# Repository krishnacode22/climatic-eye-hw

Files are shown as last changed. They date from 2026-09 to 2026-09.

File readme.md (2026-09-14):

# Climatic Eye — Solar-Powered IoT Weather Station

An open-source, solar-powered environmental monitoring station built around the **ESP32** microcontroller. Climatic Eye collects real-time weather and soil data, transmits it wirelessly over **LoRa** (RA-02 433 MHz), and serves a live debug dashboard over Wi-Fi — all without requiring an internet connection.

**Author:** Krishna Singh

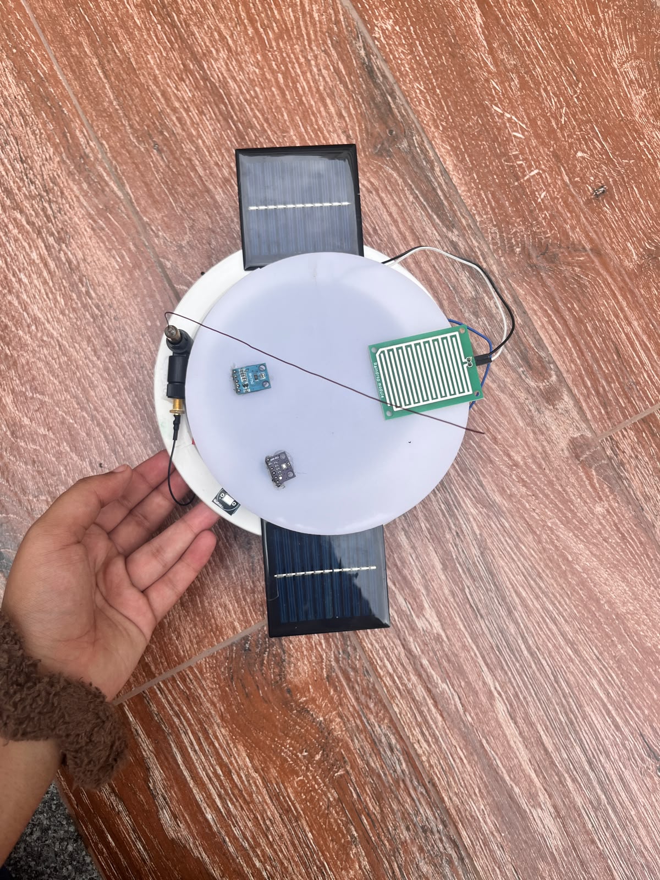
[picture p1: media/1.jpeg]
Top view — sensors and solar panels mounted on the enclosure


---

## Table of Contents

- [Features](#features)
- [Build Gallery](#build-gallery)
- [Hardware Components](#hardware-components)
- [Wiring and Pin Map](#wiring-and-pin-map)
- [Software Overview](#software-overview)
- [Getting Started](#getting-started)
- [Viewing the Schematic in Fritzing](#viewing-the-schematic-in-fritzing)
- [Repository Structure](#repository-structure)
- [Sensor Calibration](#sensor-calibration)
- [License](#license)
- [Contributing](#contributing)

---

## Features

- **Multi-sensor environmental monitoring** — temperature, humidity, barometric pressure, ambient light, rainfall, soil moisture, and GPS location.
- **LoRa long-range telemetry** — transmits JSON sensor packets via RA-02 (433 MHz) for remote data collection.
- **Solar-powered** — dual solar panels with Li-ion 18650 battery backup and TP4056 charge controller.
- **Built-in Wi-Fi dashboard** — the ESP32 hosts a responsive admin/debug web page accessible from any phone or laptop.
- **Self-contained operation** — creates its own Wi-Fi hotspot (AP mode) by default; optionally connects to an existing router (STA mode).
- **GPS geotagging** — each telemetry packet includes latitude, longitude, and satellite count from a NEO-6M GPS module.
- **Interpreted conditions** — firmware translates raw readings into human-readable states (e.g. "Comfortable", "Rain detected", "Overcast").

---

## Build Gallery

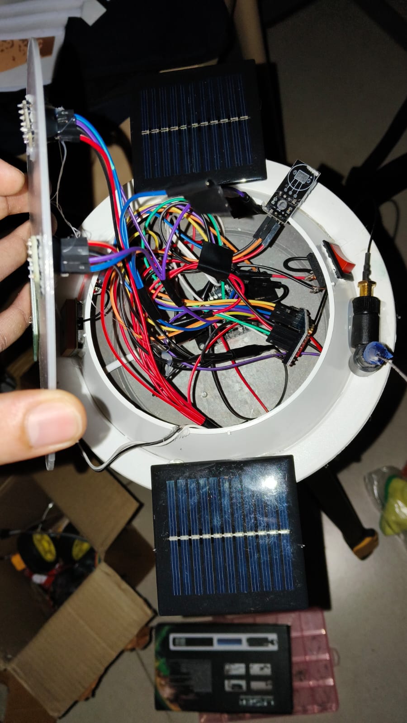
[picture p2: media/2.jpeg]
Internal wiring — ESP32, sensors, and LoRa module inside the enclosure


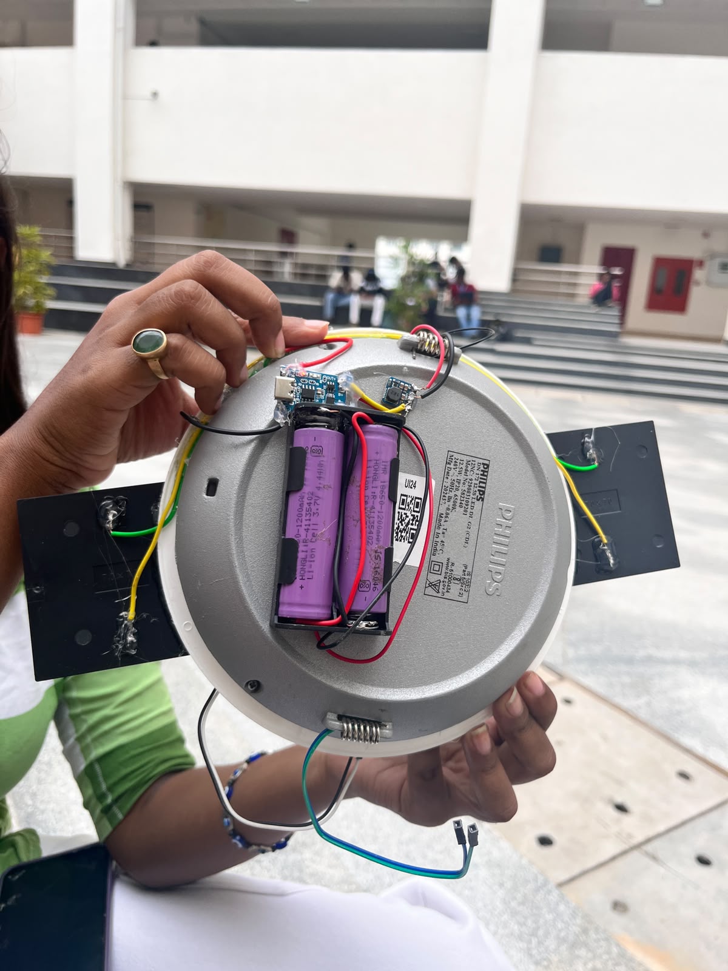
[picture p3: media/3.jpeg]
Power system — 18650 Li-ion batteries with TP4056 charge controller and solar panels


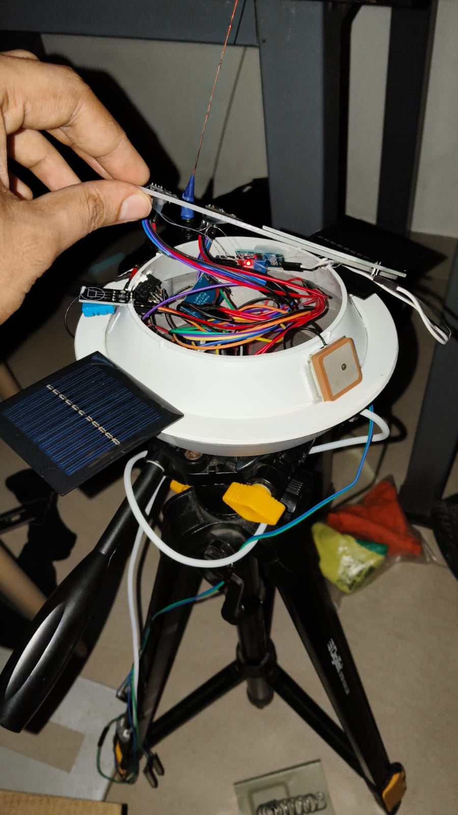
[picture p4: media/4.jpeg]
Assembled prototype on tripod — internal view with GPS antenna visible


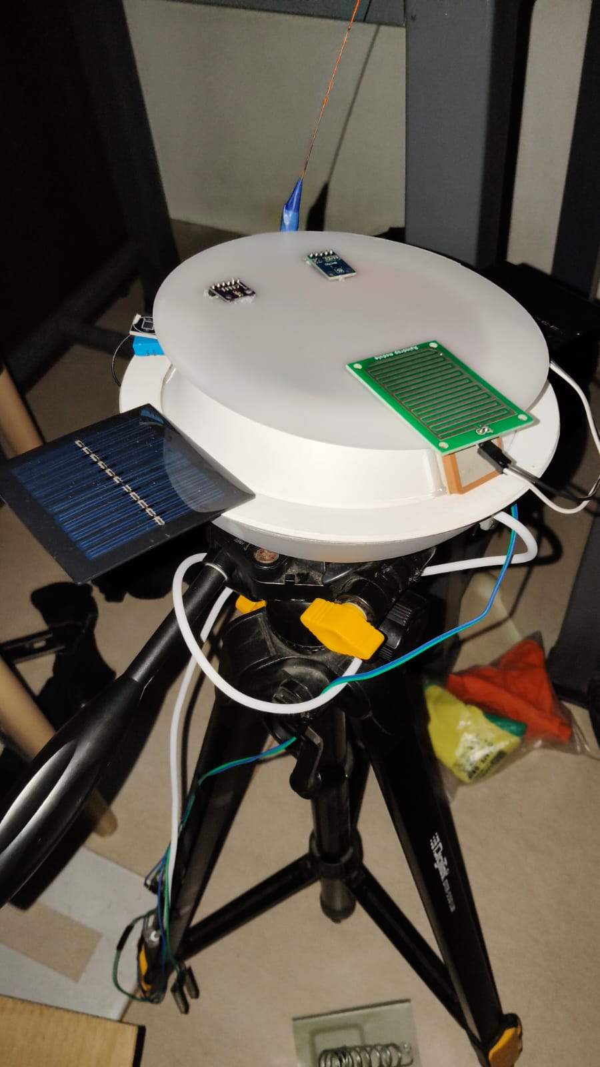
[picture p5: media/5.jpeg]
Completed unit on tripod — top view showing sensor plate, rain sensor, and solar panel


---

## Hardware Components

| Component | Purpose |
|---|---|
| ESP32 DevKit | Main microcontroller (Wi-Fi + BLE) |
| DHT11 | Temperature and humidity sensing |
| BMP280 | Barometric pressure and altitude |
| BH1750 | Ambient light intensity (lux) |
| Raindrop sensor (YL-83) | Rainfall detection (analog) |
| Soil moisture sensor (FC-28) | Soil moisture level (analog) |
| NEO-6M GPS | Latitude, longitude, and satellite tracking |
| RA-02 LoRa (SX1278) | 433 MHz long-range radio transmission |
| TP4056 charge module | Li-ion battery charging from solar input |
| 18650 Li-ion batteries (x2) | Rechargeable power supply |
| Solar panels (x2) | Energy harvesting |

---

## Wiring and Pin Map

### I2C Bus (BMP280 and BH1750)

| Signal | ESP32 GPIO |
|---|---|
| SDA | GPIO 21 |
| SCL | GPIO 22 |

### NEO-6M GPS (UART2)

| Signal | ESP32 GPIO |
|---|---|
| GPS TX | GPIO 16 (RX2) |
| GPS RX | GPIO 17 (TX2) |

### DHT11

| Signal | ESP32 GPIO |
|---|---|
| DATA | GPIO 27 |

### Analog Sensors

| Signal | ESP32 GPIO |
|---|---|
| Rain AO | GPIO 34 |
| Soil AO | GPIO 35 |

### RA-02 LoRa (SPI)

| Signal | ESP32 GPIO |
|---|---|
| SCK | GPIO 18 |
| MISO | GPIO 19 |
| MOSI | GPIO 23 |
| NSS (CS) | GPIO 5 |
| RESET | GPIO 14 |
| DIO0 | GPIO 26 |

> A Fritzing schematic (`.fzz`) and exported wiring diagrams are available in the [`hardware/`](hardware/) folder. See [Viewing the Schematic in Fritzing](#viewing-the-schematic-in-fritzing) for installation instructions.

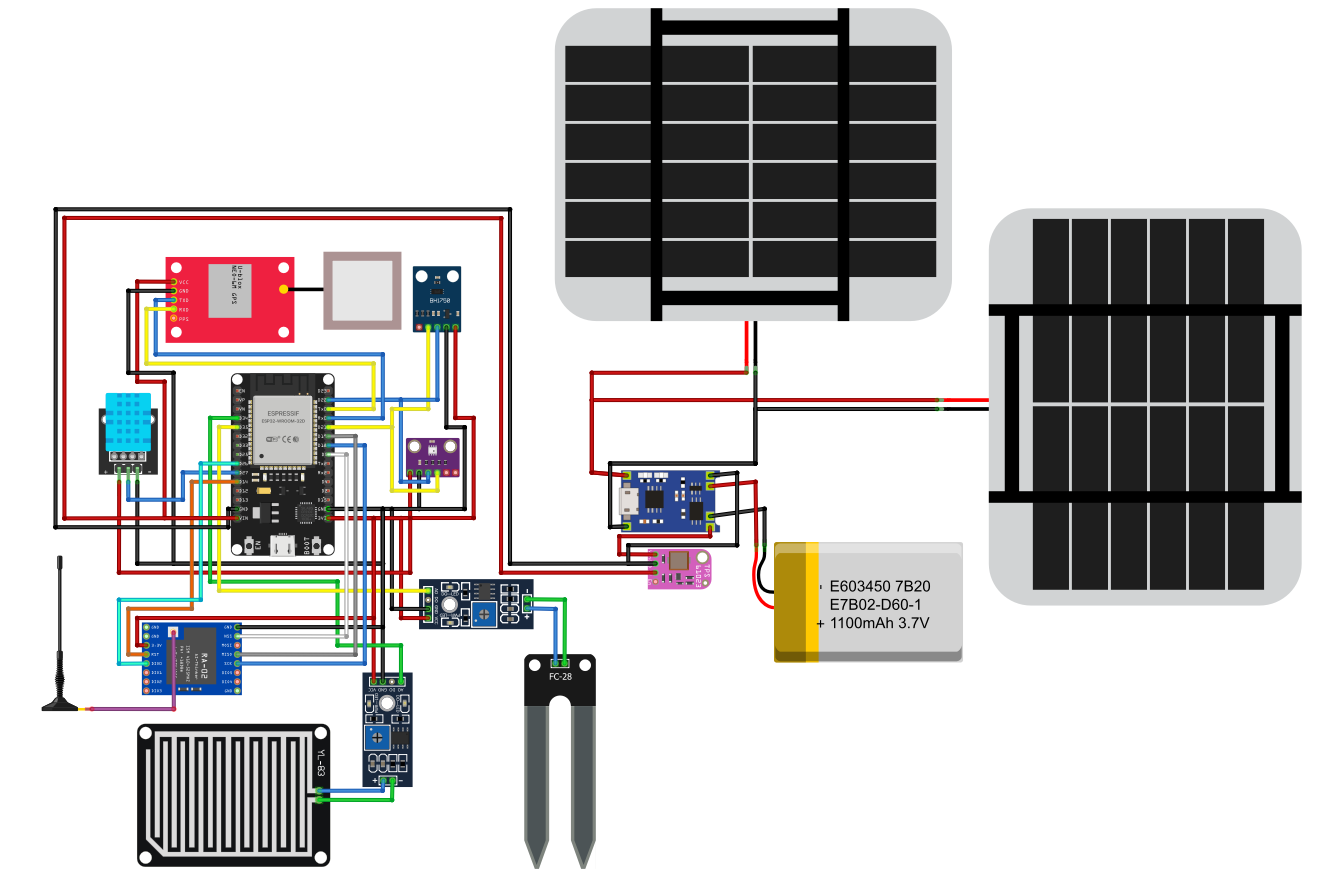
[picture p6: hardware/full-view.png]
Full circuit schematic


---

## Software Overview

### Firmware — [`ClimaticEye_Admin_Debug.ino`](software/ClimaticEye_Admin_Debug.ino)

The Arduino sketch performs the following operations:

1. **Sensor initialisation** — auto-detects BMP280 at address `0x76` or `0x77`, initialises BH1750, DHT11, GPS, and LoRa.
2. **Periodic reading** — samples all sensors every 5 seconds.
3. **JSON telemetry** — constructs a complete JSON payload containing raw values, interpreted states, and system status.
4. **LoRa transmission** — sends the JSON packet over 433 MHz LoRa.
5. **Wi-Fi web server** — serves the admin debug dashboard and exposes a `/api/data` JSON endpoint.
6. **Serial output** — prints formatted telemetry to the Serial Monitor at 115200 baud.

### Web Dashboard — [`index.html`](software/index.html)

A responsive, dark-themed, single-page dashboard that:

- Polls `/api/data` every 2 seconds.
- Displays live sensor readings with interpreted conditions.
- Shows system and sensor status (OK / FAILED) for each module.
- Provides raw ADC values and GPS coordinates.
- Includes a raw ESP32 diagnostic log panel.

### Required Arduino Libraries

| Library | Source |
|---|---|
| `WiFi` | Built-in (ESP32 core) |
| `WebServer` | Built-in (ESP32 core) |
| `Wire` / `SPI` | Built-in (Arduino core) |
| `Adafruit BMP280` | Adafruit BMP280 Library |
| `BH1750` | BH1750 by Christopher Laws |
| `DHT sensor library` | DHT sensor library by Adafruit |
| `TinyGPSPlus` | TinyGPSPlus by Mikal Hart |
| `LoRa` | LoRa by Sandeep Mistry |

---

## Getting Started

### 1. Clone the Repository

```bash
git clone https://github.com/<your-username>/climatic-eye-hw.git
```

### 2. Wire the Hardware

Follow the pin map above or refer to the [Climatic_Eye_Connection_Guide.pdf](hardware/Climatic_Eye_Connection_Guide.pdf) in the `hardware/` folder.

### 3. Flash the Firmware

1. Open [`software/ClimaticEye_Admin_Debug.ino`](software/ClimaticEye_Admin_Debug.ino) in the **Arduino IDE**.
2. Install the ESP32 board package and the required libraries listed above.
3. Select board: **ESP32 Dev Module**.
4. Set baud rate: **115200**.
5. Upload.

### 4. Access the Dashboard

By default the ESP32 creates a Wi-Fi hotspot with the following credentials:

| Setting | Value |
|---|---|
| SSID | `ClimaticEye-Debug` |
| Password | `climatic123` |
| Dashboard URL | `http://192.168.4.1` |

To connect to an existing router instead, set `STA_SSID` and `STA_PASSWORD` in the sketch before uploading. The ESP32 will attempt STA mode first and fall back to AP mode if the connection fails.

### 5. LoRa Frequency

The default LoRa frequency is **433 MHz** (`433E6`). If your RA-02 module operates at a different frequency, update the `LORA_FREQUENCY` constant in the sketch accordingly (e.g. `868E6` or `915E6`).

---

## Viewing the Schematic in Fritzing

The circuit schematic is provided as a [Fritzing](https://fritzing.org/) project file (`hardware/climatic-eye-schematic.fzz`). Fritzing is an open-source electronics design tool used to create breadboard layouts, schematics, and PCB designs.

### Installing Fritzing

1. Visit the official Fritzing download page: **[https://fritzing.org/download/](https://fritzing.org/download/)**
2. Fritzing is available for **Windows**, **macOS**, and **Linux**. Select the appropriate installer for your operating system.
3. Fritzing is distributed as a paid download (a small donation is requested to support ongoing development). Alternatively, the source code can be compiled from the [Fritzing GitHub repository](https://github.com/fritzing/fritzing-app).
4. Download and run the installer, or extract the portable archive to a directory of your choice.

### Opening the Schematic

1. Launch Fritzing.
2. Go to **File > Open** and navigate to `hardware/climatic-eye-schematic.fzz`.
3. The project will open in the **Breadboard** view. Use the tabs at the top to switch between **Breadboard**, **Schematic**, and **PCB** views.

Pre-exported wiring diagrams are also available as PNG images in the `hardware/` folder for those who prefer not to install Fritzing:

- [`full-view.png`](hardware/full-view.png) — complete circuit overview
- [`zoomed-esp32.png`](hardware/zoomed-esp32.png) — ESP32 wiring detail
- [`zoomed-power.png`](hardware/zoomed-power.png) — power circuit detail

---

## Repository Structure

```
climatic-eye-hw/
├── hardware/
│   ├── climatic-eye-schematic.fzz          # Fritzing schematic source file
│   ├── full-view.png                       # Full circuit diagram (exported)
│   ├── zoomed-esp32.png                    # ESP32 wiring detail (exported)
│   ├── zoomed-power.png                    # Power circuit detail (exported)
│   └── Climatic_Eye_Connection_Guide.pdf   # Printable wiring guide
├── software/
│   ├── ClimaticEye_Admin_Debug.ino         # ESP32 Arduino firmware
│   ├── index.html                          # Standalone web dashboard
│   └── setup-guide.png                     # Setup reference image
├── media/
│   ├── 1.jpeg                              # Build and prototype photographs
│   ├── 2.jpeg
│   ├── 3.jpeg
│   ├── 4.jpeg
│   └── 5.jpeg
└── readme.md
```

---

## Sensor Calibration

The raindrop and soil moisture sensors use analog ADC readings that must be calibrated for the specific modules in use. The default values in the firmware are as follows:

| Parameter | Default Value | Description |
|---|---|---|
| `RAIN_DRY_ADC` | 4095 | ADC reading when the rain sensor surface is dry |
| `RAIN_WET_ADC` | 1200 | ADC reading when the rain sensor surface is fully wet |
| `SOIL_DRY_ADC` | 3200 | ADC reading when the soil probe is in dry soil |
| `SOIL_WET_ADC` | 1400 | ADC reading when the soil probe is in saturated soil |

If the sensor readings are inverted (i.e. a wetter condition produces a higher ADC value), swap the DRY and WET values for the corresponding sensor.

---

## License

This project is open source. You are free to use, modify, and distribute it.

---

## Contributing

Contributions, bug reports, and feature requests are welcome. Please open an issue or submit a pull request.

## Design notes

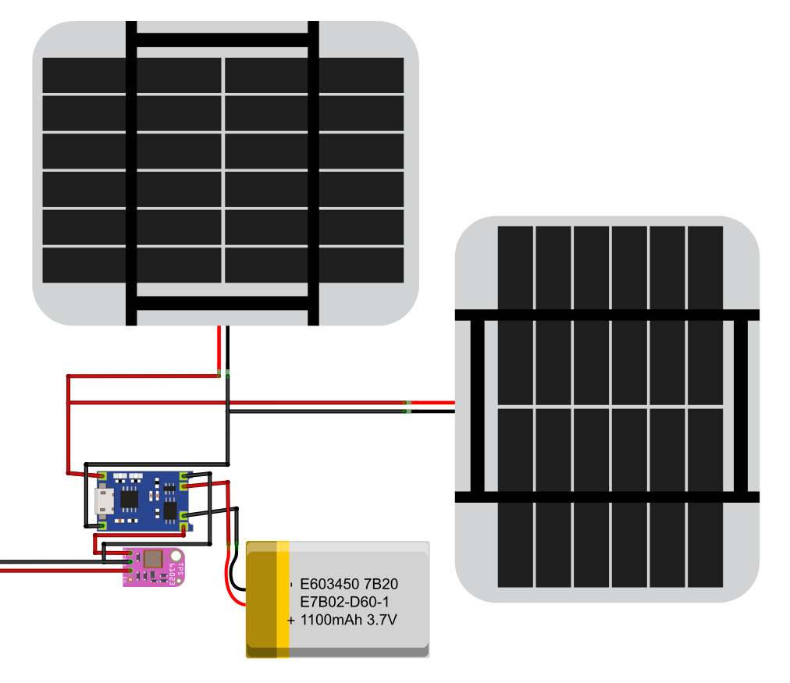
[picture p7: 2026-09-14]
hardware/zoomed-power.png

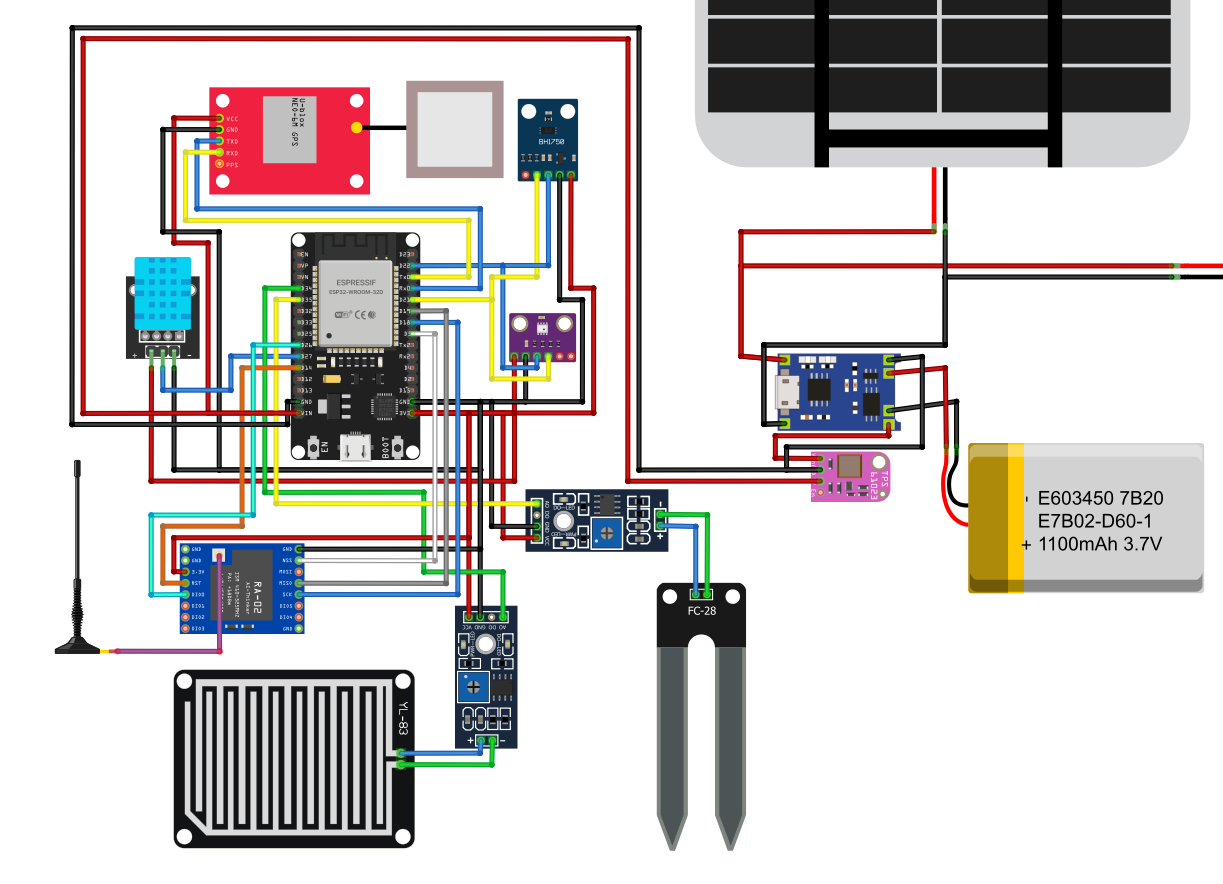
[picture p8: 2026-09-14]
hardware/zoomed-esp32.png

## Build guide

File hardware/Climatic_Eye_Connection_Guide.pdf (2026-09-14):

Climatic Eye | Hardware Connection Guide | Page 1

# CLIMATIC EYE

## Hardware Connection & Power Integration Guide

## ESP32-based environmental monitoring node

SYSTEM | CONFIGURATION
Controller | Generic 30-pin ESP32 DevKit
Environmental sensing | BMP280, BH1750, DHT11
Field sensing | Raindrop sensor, soil-moisture sensor
Positioning | NEO-6M GPS
Wireless link | RA-02 LoRa
Power | Solar panels, TP4056, Li-ion battery, 5 V boost converter

Document purpose
Use this guide as the wiring reference during assembly and bench testing. The GPIO allocation is kept consistent with the Climatic Eye firmware and admin debug dashboard.
Revision: Prototype Integration Guide | Bench assembly and field-node development

# 1. System Overview

The node combines environmental sensors, GPS, LoRa communications, and a solar-charged battery supply around a generic 30-pin ESP32. BMP280 and BH1750 share the I²C bus. The NEO-6M uses a dedicated hardware UART. The RA-02 uses the ESP32 VSPI pins. The raindrop and soil sensors use ADC inputs.

## Functional architecture

Solar panels → TP4056 → Li-ion battery → 5 V boost converter → ESP32 VIN/5V → ESP32 3.3 V rail → sensors + RA-02

Core rule
Keep all grounds common. Keep the RA-02 on 3.3 V only. Verify the boost-converter output with a multimeter before connecting it to the ESP32.

# 2. Complete GPIO Assignment

Device | Signal | ESP32 GPIO | Interface / note
BMP280 | SDA | GPIO 21 | I²C
BMP280 | SCL | GPIO 22 | I²C
BH1750 | SDA | GPIO 21 | Shares I²C with BMP280
BH1750 | SCL | GPIO 22 | Shares I²C with BMP280
NEO-6M | TX | GPIO 16 | ESP32 UART2 RX
NEO-6M | RX | GPIO 17 | ESP32 UART2 TX
DHT11 | DATA | GPIO 27 | Digital input
Raindrop module | AO | GPIO 34 | ADC input-only
Raindrop module | DO | Not connected | Analog reading used
Soil moisture module | AO | GPIO 35 | ADC input-only
Soil moisture module | DO | Not connected | Analog reading used
RA-02 | SCK | GPIO 18 | VSPI
RA-02 | MISO | GPIO 19 | VSPI
RA-02 | MOSI | GPIO 23 | VSPI
RA-02 | NSS / CS | GPIO 5 | Chip select
RA-02 | RESET | GPIO 14 | Reset control
RA-02 | DIO0 | GPIO 26 | LoRa interrupt

# 3. Sensor Connections

## 3.1 BMP280

BMP280 pin | ESP32 connection | Instruction
VCC / VIN | 3.3 V | Use 3.3 V.
GND | GND | Common ground.
SDA | GPIO 21 | I²C data.
SCL | GPIO 22 | I²C clock.

## 3.2 BH1750

BH1750 pin | ESP32 connection | Instruction
VCC | 3.3 V | Use 3.3 V.
GND | GND | Common ground.
SDA | GPIO 21 | Shares SDA with BMP280.
SCL | GPIO 22 | Shares SCL with BMP280.

I²C bus
BMP280 and BH1750 are connected in parallel on GPIO 21/22. If either is not detected, check power, ground, SDA/SCL orientation, and run an I²C scanner.

## 3.3 DHT11

DHT11 pin | ESP32 connection | Instruction
VCC | 3.3 V | Use 3.3 V.
GND | GND | Common ground.
DATA | GPIO 27 | Digital data line.

For a bare 4-pin DHT11, add approximately a 10 kΩ pull-up resistor between DATA and 3.3 V. Common 3-pin DHT11 modules normally include the pull-up resistor.

## 3.4 Raindrop sensor module

Module pin | ESP32 connection | Instruction
VCC | 3.3 V | Prefer 3.3 V so AO stays within the ESP32 ADC range.
GND | GND | Common ground.
AO | GPIO 34 | Analog measurement.
DO | Not connected | Not used by current firmware.

## 3.5 Soil-moisture sensor

Module pin | ESP32 connection | Instruction
VCC | 3.3 V | Prefer 3.3 V for ADC compatibility.
GND | GND | Common ground.

Module pin | ESP32 connection | Instruction
AO | GPIO 35 | Analog measurement.
DO | Not connected | Not used by current firmware.

# 4. GPS and LoRa Connections

## 4.1 NEO-6M GPS

NEO-6M pin | ESP32 connection | Instruction
VCC | 5 V/VIN or module-specified supply | Verify the exact breakout board.
GND | GND | Common ground.
TX | GPIO 16 | GPS TX → ESP32 UART2 RX.
RX | GPIO 17 | ESP32 UART2 TX → GPS RX.

GPS fix
Initial position acquisition can take time. Test outdoors or near a window with a clear sky view. A valid module can output NMEA data before obtaining a position fix.

## 4.2 RA-02 LoRa

RA-02 pin | ESP32 connection | Instruction
VCC | 3.3 V ONLY | Never connect to 5 V.
GND | GND | Common ground.
SCK | GPIO 18 | VSPI clock.
MISO | GPIO 19 | VSPI MISO.
MOSI | GPIO 23 | VSPI MOSI.
NSS / CS | GPIO 5 | Chip select.
RESET | GPIO 14 | Reset control.
DIO0 | GPIO 26 | Required by current firmware.
DIO1–DIO5 | Not connected | Not required by current firmware.

RA-02 protection
Use a stable 3.3 V supply. Keep the antenna connected whenever transmitting. A local 100 µF capacitor across RA-02 3.3 V and GND is recommended to reduce supply dips during TX.

## LoRa frequency

The firmware currently uses 433E6 as the default frequency. Change it only if your actual RA-02 hardware and legal operating band require another frequency. The receiver must use the same frequency and compatible radio settings.

# 5. Solar, Charging, Battery and Boost Connections

The prototype power path uses a single-cell Li-ion battery and a 5 V boost converter. The TP4056 is a single-cell Li-ion charger, so the battery arrangement must remain a 1-cell nominal system.

## 5.1 Solar panels → TP4056

Solar connection | TP4056 | Instruction
Panel 1 + | IN+ | Positive input.
Panel 1 − | IN− | Negative input.
Panel 2 + | IN+ | Parallel positive connection.
Panel 2 − | IN− | Parallel negative connection.

The two panels are intended to be connected in parallel for the prototype. Do not connect them in series unless the resulting voltage has been verified as suitable for the specific charger.

## 5.2 TP4056 → battery

TP4056 | Battery / load | Instruction
B+ | Battery + | Battery positive.
B− | Battery − | Battery negative.
OUT+ | Booster IN+ | Load output positive.
OUT− | Booster IN− | Load output negative.

Two-cell warning
Do not connect two 3.7 V cells in series to a standard single-cell TP4056. If two compatible cells are used with this charger, they must form a properly matched parallel 1S2P pack, with both cells at essentially the same voltage before paralleling.

## 5.3 Booster → ESP32

Booster | ESP32 | Instruction
OUT+ | VIN / 5V | Feed approximately 5.0 V.
OUT− | GND | Common ground.

Mandatory pre-power check
Before connecting the booster to the ESP32, measure its output with a multimeter and set it to approximately 5.0 V. Do not connect an unknown or unadjusted boost output to the ESP32 VIN/5V input.

## 5.4 ESP32 3.3 V distribution

Use the ESP32 3.3 V rail for BMP280, BH1750, DHT11, raindrop module, soil-moisture module, and RA-02 as specified in this guide.

# 6. Power Architecture Reference

Solar Panel 1 + ■■
Solar Panel 2 + ■■■■ TP4056 IN+
Solar Panel 1 − ■■
Solar Panel 2 − ■■■■ TP4056 IN−

TP4056 B+ ■■■■■■■■■ Battery + TP4056 B− ■■■■■■■■■ Battery −

TP4056 OUT+ ■■■■■■■ Booster IN+ TP4056 OUT− ■■■■■■■ Booster IN−

Booster OUT+ ■■■■■■ ESP32 VIN / 5V Booster OUT− ■■■■■■ ESP32 GND

ESP32 3.3V ■■■■■■■■■ Sensors + RA-02 ESP32 GND ■■■■■■■■■■ All grounds

# 7. Assembly and Power-Up Procedure

Step | Action
1 | Inspect every module and confirm its pin labels before wiring.
2 | Verify solar-panel polarity with a multimeter.
3 | Connect the solar panels to TP4056 IN+ / IN− in parallel.
4 | Connect the Li-ion battery to TP4056 B+ / B− using a suitable single-cell configuration.
5 | Connect TP4056 OUT+ / OUT− to the booster input.
6 | Power the booster and adjust its output to approximately 5.0 V.
7 | With power removed, connect booster output to ESP32 VIN/5V and GND.
8 | Connect the 3.3 V sensor rail and common grounds.
9 | Connect I²C sensors, DHT11, analog sensors, and GPS.
10 | Connect the RA-02 last. Confirm 3.3 V supply and attach the antenna.
11 | Power the node and check Serial Monitor at 115200 baud.
12 | Verify sensor initialization and LoRa status before field use.

# 8. Verification Checklist

Check | Expected result
ESP32 supply | Approximately 5.0 V at VIN/5V input.
ESP32 3.3 V rail | Stable 3.3 V output.
BMP280 | Detected at I²C address 0x76 or 0x77.
BH1750 | Detected and produces non-negative lux readings.
DHT11 | Temperature and humidity readings are valid.
Raindrop | GPIO 34 ADC value changes when the plate becomes wet.
Soil sensor | GPIO 35 ADC value changes between dry and wet conditions.

Check | Expected result
GPS | NMEA data appears; valid fix may require outdoor sky view.
RA-02 | Initializes and transmits with antenna attached.
Web debug page | ESP32 hotspot or configured Wi-Fi provides access.

# 9. Important Notes, Exceptions and Fallbacks

## Sensor failure handling

Unavailable readings must remain unavailable rather than being replaced by fabricated values. The admin debug page uses N/A when a reading cannot be obtained. A missing GPS fix is represented separately from a GPS hardware failure.

## Analog sensor calibration

Rain and soil percentages depend on calibration. Record actual raw ADC values under known dry and wet conditions, then update the firmware calibration constants. Retain raw ADC values for diagnostics.

## Power fallback

If the solar supply is weak, the TP4056 may not charge effectively. For final outdoor deployment, use a charger/power-path solution designed for solar input rather than relying on a conventional TP4056 as the complete solar power-management system.

## Common faults

Symptom | First checks
ESP32 resets during LoRa TX | RA-02 supply stability, common ground, local 100 µF capacitor, antenna, booster capacity.
BMP280/BH1750 not detected | 3.3 V, GND, SDA GPIO 21, SCL GPIO 22, I²C address.
DHT11 errors | DATA GPIO 27, pull-up for bare sensor, timing, 3.3 V supply.
Rain/soil percentage wrong | Check raw ADC first; recalibrate dry/wet endpoints.
GPS has no fix | Allow acquisition time; use outdoor/clear-sky position.
LoRa initialization fails | 3.3 V, CS GPIO 5, RESET GPIO 14, DIO0 GPIO 26, SPI pins, frequency.
ESP32 will not boot | Disconnect peripherals, verify power rails, reconnect modules one at a time.
Boost output too high | Disconnect ESP32 immediately; adjust booster using a multimeter.

## Design constraints

Constraint | Rule
RA-02 supply | 3.3 V only.
GPIO 34 / 35 | Input-only; use for ADC sensors.
GPIO 6–11 | Do not use; associated with ESP32 flash on typical modules.
TP4056 | Single-cell Li-ion charging architecture.
Battery paralleling | Only suitable matched cells at essentially equal voltage.
USB + external supply | Avoid simultaneous USB and external VIN/5V unless the exact board power path is verified.

Final pre-deployment check
Run the complete node from the intended battery and booster for an extended bench test. Confirm sensor readings, LoRa transmission, GPS acquisition, ESP32 stability, charging behavior, and enclosure ventilation before field installation.

# 10. Firmware and Debug Interface

The current debug firmware exposes structured telemetry suitable for later dashboard integration. Principal fields include node_id, packet, temperature, humidity, pressure, altitude, light_lux, rain_raw, rain_percent, soil_raw, soil_percent, gps_fix, latitude, longitude, satellites, sensor status flags, and LoRa transmission status.

The ESP32 admin debug page is a temporary local diagnostic interface. When no router credentials are configured, the ESP32 creates the ClimaticEye-Debug access point and serves the page at its local access-point address.

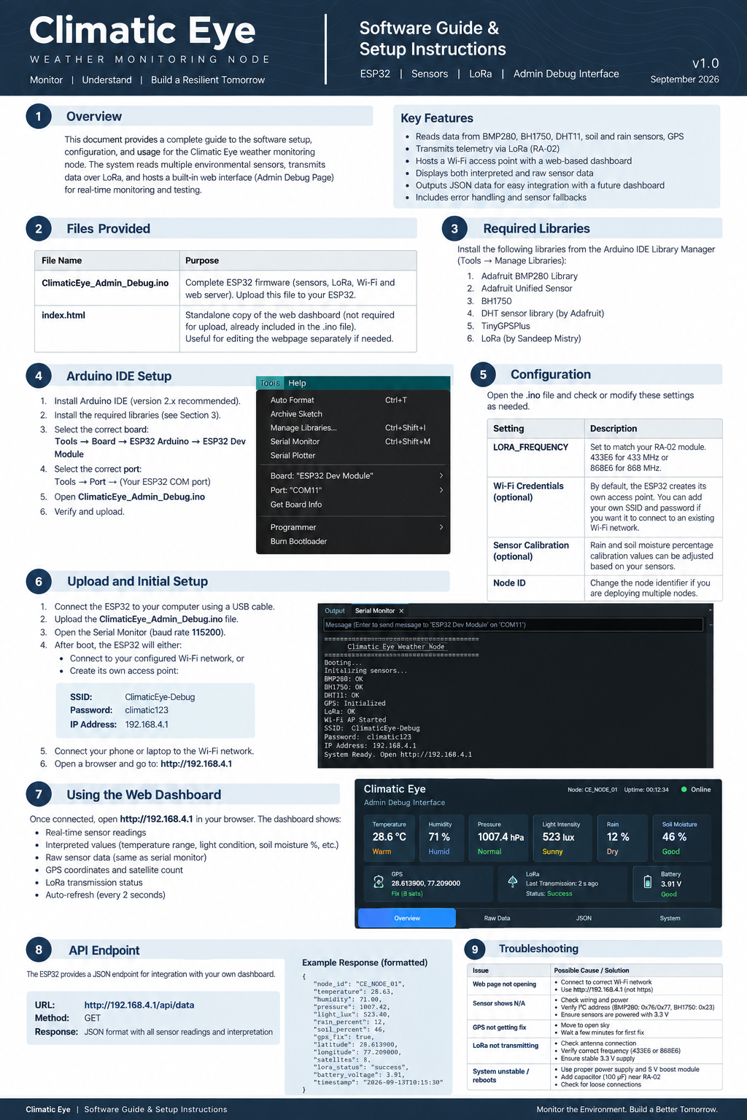
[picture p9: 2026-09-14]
software/setup-guide.png

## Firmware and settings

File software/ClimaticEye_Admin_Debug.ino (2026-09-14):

#include <WiFi.h>
#include <WebServer.h>
#include <SPI.h>
#include <Wire.h>
#include <Adafruit_BMP280.h>
#include <BH1750.h>
#include <DHT.h>
#include <TinyGPS++.h>
#include <LoRa.h>

// ============================================================
// CLIMATIC EYE - COMPLETE SENSOR + LORA + ADMIN DEBUG SERVER
// ============================================================
// Same sensor/LoRa wiring as the previous version.
//
// I2C:
//   SDA  -> GPIO 21
//   SCL  -> GPIO 22
//
// GPS:
//   GPS TX -> GPIO 16
//   GPS RX -> GPIO 17
//
// DHT11:
//   DATA -> GPIO 27
//
// Analog:
//   Rain AO -> GPIO 34
//   Soil AO -> GPIO 35
//
// RA-02:
//   SCK   -> GPIO 18
//   MISO  -> GPIO 19
//   MOSI  -> GPIO 23
//   NSS   -> GPIO 5
//   RESET -> GPIO 14
//   DIO0  -> GPIO 26
//
// IMPORTANT:
// Change LORA_FREQUENCY to match the actual RA-02 hardware.
// 433 MHz: 433E6
// 868 MHz: 868E6
// ============================================================


// ===================== PIN DEFINITIONS ======================

#define SDA_PIN 21
#define SCL_PIN 22

#define GPS_RX 16
#define GPS_TX 17

#define DHT_PIN 27
#define DHT_TYPE DHT11

#define RAIN_PIN 34
#define SOIL_PIN 35

#define LORA_SCK 18
#define LORA_MISO 19
#define LORA_MOSI 23
#define LORA_CS 5
#define LORA_RST 14
#define LORA_DIO0 26


// ======================= LORA SETTINGS ======================

#define LORA_FREQUENCY 433E6
#define LORA_SYNC_WORD 0x12


// ==================== CALIBRATION SETTINGS ==================
// These are SAFE STARTING VALUES only.
// Calibrate them using your actual sensors.
//
// For these common analog modules:
//     DRY usually produces a higher ADC value.
//     WET usually produces a lower ADC value.
//
// If your sensor behaves in the opposite direction, swap the
// DRY and WET values.

#define RAIN_DRY_ADC 4095
#define RAIN_WET_ADC 1200

#define SOIL_DRY_ADC 3200
#define SOIL_WET_ADC 1400


// ====================== WIFI SETTINGS ========================
// The ESP32 creates its own Wi-Fi hotspot by default.
// No router or internet connection is required.
//
// Connect phone/laptop to:
//     SSID:     ClimaticEye-Debug
//     Password: climatic123
//
// Then open:
//     http://192.168.4.1
//
// You can optionally enter a router's credentials below.
// The sketch will try STA first and fall back to the AP.

const char* STA_SSID = "";
const char* STA_PASSWORD = "";

const char* AP_SSID = "ClimaticEye-Debug";
const char* AP_PASSWORD = "climatic123";


// ========================= OBJECTS ===========================

Adafruit_BMP280 bmp;
BH1750 lightMeter;
DHT dht(DHT_PIN, DHT_TYPE);

HardwareSerial GPS(2);
TinyGPSPlus gps;

WebServer server(80);


// ========================= STATE =============================

bool bmpOK = false;
bool bh1750OK = false;
bool dhtOK = false;
bool loraOK = false;

bool lastLoraSent = false;

bool dhtReadingOK = false;
bool bmpReadingOK = false;
bool bh1750ReadingOK = false;

unsigned long packetNumber = 0;
unsigned long lastMeasurementMillis = 0;

float temperature = NAN;
float humidity = NAN;

float bmpTemperature = NAN;
float pressure = NAN;
float altitude = NAN;

float lightLux = NAN;

int rainRaw = 0;
int soilRaw = 0;

float rainPercent = NAN;
float soilPercent = NAN;

bool gpsFix = false;
double latitude = 0.0;
double longitude = 0.0;
int satellites = 0;

String lastTelemetryJSON = "{}";
String lastRawLog = "";
String lastError = "";

String wifiMode = "AP";
String wifiIP = "192.168.4.1";


// ===================== WEB PAGE ==============================

const char INDEX_HTML[] PROGMEM = R"rawliteral(
<!doctype html>
<html lang="en">
<head>
<meta charset="utf-8">
<meta name="viewport" content="width=device-width,initial-scale=1">
<title>Climatic Eye - Admin Debug</title>
<style>
:root{
 --bg:#0b1220;--panel:#111827;--panel2:#0f172a;
 --text:#e5e7eb;--muted:#94a3b8;--border:#263244;
 --ok:#22c55e;--warn:#f59e0b;--bad:#ef4444;--info:#60a5fa;
}
*{box-sizing:border-box}
body{margin:0;background:var(--bg);color:var(--text);
font-family:Arial,Helvetica,sans-serif}
.wrap{max-width:1250px;margin:0 auto;padding:24px}
header{display:flex;justify-content:space-between;gap:16px;
align-items:flex-start;margin-bottom:20px}
h1{margin:0 0 6px;font-size:28px}
.subtitle{color:var(--muted)}
.status{padding:8px 12px;border-radius:8px;border:1px solid var(--border);
background:var(--panel);font-size:13px;white-space:nowrap}
.grid{display:grid;grid-template-columns:repeat(4,minmax(0,1fr));gap:12px}
.card{background:var(--panel);border:1px solid var(--border);
border-radius:12px;padding:16px;min-width:0}
.label{color:var(--muted);font-size:12px;text-transform:uppercase;
letter-spacing:.08em}
.value{font-size:26px;font-weight:700;margin-top:7px}
.unit{color:var(--muted);font-size:13px}
.interp{margin-top:8px;font-size:13px}
.section{margin-top:20px}
.section h2{margin:0 0 10px;font-size:18px}
.rows{display:grid;grid-template-columns:repeat(2,minmax(0,1fr));gap:10px}
.row{background:var(--panel2);border:1px solid var(--border);
border-radius:10px;padding:12px;display:flex;justify-content:space-between;
gap:16px}
.row span:first-child{color:var(--muted)}
.badge{display:inline-block;padding:4px 8px;border-radius:999px;
font-size:12px;font-weight:700;border:1px solid var(--border)}
.ok{color:var(--ok)}.warn{color:var(--warn)}.bad{color:var(--bad)}
.info{color:var(--info)}
pre{margin:0;background:#060b14;border:1px solid var(--border);
border-radius:10px;padding:14px;white-space:pre-wrap;word-break:break-word;
overflow:auto;min-height:260px;color:#d1d5db;font-family:Consolas,Monaco,monospace;
font-size:13px;line-height:1.45}
.error{margin-top:10px;color:var(--bad);font-size:13px}
.footer{margin-top:18px;color:var(--muted);font-size:12px}
@media(max-width:950px){.grid{grid-template-columns:repeat(2,1fr)}}
@media(max-width:600px){.wrap{padding:14px}header{flex-direction:column}
.grid,.rows{grid-template-columns:1fr}}
</style>
</head>
<body>
<div class="wrap">

<header>
<div>
<h1>Climatic Eye · Admin Debug</h1>
<div class="subtitle">Live local telemetry, interpreted conditions and raw ESP32 diagnostics</div>
</div>
<div id="connection" class="status">Connecting…</div>
</header>

<section class="grid">

<div class="card">
<div class="label">Temperature</div>
<div id="temperature" class="value">--</div>
<div class="unit">°C</div>
<div id="temperatureInterp" class="interp">Waiting…</div>
</div>

<div class="card">
<div class="label">Humidity</div>
<div id="humidity" class="value">--</div>
<div class="unit">%</div>
<div id="humidityInterp" class="interp">Waiting…</div>
</div>

<div class="card">
<div class="label">Pressure</div>
<div id="pressure" class="value">--</div>
<div class="unit">hPa</div>
<div id="pressureInterp" class="interp">Waiting…</div>
</div>

<div class="card">
<div class="label">Sky Condition</div>
<div id="sky" class="value">--</div>
<div class="unit">interpreted from BH1750</div>
<div id="lightInterp" class="interp">Waiting…</div>
</div>

<div class="card">
<div class="label">Rain</div>
<div id="rain" class="value">--</div>
<div class="unit">%</div>
<div id="rainInterp" class="interp">Waiting…</div>
</div>

<div class="card">
<div class="label">Soil Moisture</div>
<div id="soil" class="value">--</div>
<div class="unit">%</div>
<div id="soilInterp" class="interp">Waiting…</div>
</div>

<div class="card">
<div class="label">GPS</div>
<div id="gps" class="value">--</div>
<div class="unit">position fix</div>
<div id="gpsInterp" class="interp">Waiting…</div>
</div>

<div class="card">
<div class="label">LoRa</div>
<div id="lora" class="value">--</div>
<div class="unit">last transmission</div>
<div id="loraInterp" class="interp">Waiting…</div>
</div>

</section>

<section class="section">
<h2>System / Sensor Status</h2>
<div class="rows">
<div class="row"><span>Node ID</span><strong id="nodeId">--</strong></div>
<div class="row"><span>Packet</span><strong id="packet">--</strong></div>
<div class="row"><span>BMP280</span><strong id="bmpStatus">--</strong></div>
<div class="row"><span>BH1750</span><strong id="bhStatus">--</strong></div>
<div class="row"><span>DHT11</span><strong id="dhtStatus">--</strong></div>
<div class="row"><span>GPS</span><strong id="gpsStatus">--</strong></div>
<div class="row"><span>LoRa</span><strong id="loraStatus">--</strong></div>
<div class="row"><span>Web mode</span><strong id="wifiMode">--</strong></div>
<div class="row"><span>ESP32 IP</span><strong id="wifiIP">--</strong></div>
<div class="row"><span>Last update</span><strong id="updated">--</strong></div>
</div>
</section>

<section class="section">
<h2>Raw Sensor Readings</h2>
<div class="rows">
<div class="row"><span>Raindrop ADC</span><strong id="rainRaw">--</strong></div>
<div class="row"><span>Soil ADC</span><strong id="soilRaw">--</strong></div>
<div class="row"><span>BMP Temperature</span><strong id="bmpTempRaw">--</strong></div>
<div class="row"><span>Light</span><strong id="luxRaw">--</strong></div>
<div class="row"><span>GPS Satellites</span><strong id="satellites">--</strong></div>
<div class="row"><span>Latitude</span><strong id="latitude">--</strong></div>
<div class="row"><span>Longitude</span><strong id="longitude">--</strong></div>
</div>
</section>

<section class="section">
<h2>Raw ESP32 Diagnostic Output</h2>
<pre id="rawLog">Waiting for ESP32 data…</pre>
<div id="error" class="error"></div>
</section>

<div class="footer">
Refreshes every 2 seconds. N/A means the firmware deliberately returned a fallback value
because the source reading was unavailable.
</div>

</div>

<script>
const $=id=>document.getElementById(id);

function fmt(v,d=2){
 if(v===null||v===undefined||Number.isNaN(Number(v))) return "N/A";
 return Number(v).toFixed(d);
}

function badge(text,cls){
 return '<span class="badge '+cls+'">'+text+'</span>';
}

function render(d){
 $("temperature").textContent=fmt(d.temperature);
 $("humidity").textContent=fmt(d.humidity);
 $("pressure").textContent=fmt(d.pressure);
 $("sky").textContent=d.sky_condition||"N/A";
 $("rain").textContent=fmt(d.rain_percent);
 $("soil").textContent=fmt(d.soil_percent);

 $("temperatureInterp").textContent=d.temperature_state||"N/A";
 $("humidityInterp").textContent=d.humidity_state||"N/A";
 $("pressureInterp").textContent=d.pressure_state||"N/A";
 $("lightInterp").textContent=(d.light_lux==null?"N/A":fmt(d.light_lux)+" lux");
 $("rainInterp").textContent=d.rain_state||"N/A";
 $("soilInterp").textContent=d.soil_state||"N/A";

 if(d.gps_fix){
   $("gps").textContent="FIX";
   $("gpsInterp").innerHTML=badge((d.satellites||0)+" satellites","ok");
 }else{
   $("gps").textContent="NO FIX";
   $("gpsInterp").innerHTML=badge("Waiting for position","warn");
 }

 $("lora").textContent=d.lora_sent?"SENT":"FAILED";
 $("loraInterp").innerHTML=d.lora_sent?
   badge("Packet transmitted","ok"):badge("Last TX failed","bad");

 $("nodeId").textContent=d.node_id??"N/A";
 $("packet").textContent=d.packet??"N/A";
 $("bmpStatus").textContent=d.bmp_ok?"OK":"FAILED";
 $("bhStatus").textContent=d.bh1750_ok?"OK":"FAILED";
 $("dhtStatus").textContent=d.dht_ok?"OK":"FAILED";
 $("gpsStatus").textContent=d.gps_fix?"FIX":"NO FIX";
 $("loraStatus").textContent=d.lora_ok?(d.lora_sent?"OK / SENT":"OK / TX FAILED"):"FAILED";
 $("wifiMode").textContent=d.wifi_mode??"N/A";
 $("wifiIP").textContent=d.wifi_ip??"N/A";
 $("updated").textContent=new Date().toLocaleTimeString();

 $("rainRaw").textContent=fmt(d.rain_raw,0);
 $("soilRaw").textContent=fmt(d.soil_raw,0);
 $("bmpTempRaw").textContent=d.bmp_temperature==null?"N/A":fmt(d.bmp_temperature)+" °C";
 $("luxRaw").textContent=d.light_lux==null?"N/A":fmt(d.light_lux)+" lux";
 $("satellites").textContent=d.satellites??"N/A";
 $("latitude").textContent=d.gps_fix?fmt(d.latitude,6):"N/A";
 $("longitude").textContent=d.gps_fix?fmt(d.longitude,6):"N/A";

 $("rawLog").textContent=d.raw_log||d.raw_json||"No raw output available.";
 $("error").textContent=d.error||"";

 $("connection").textContent="ESP32 connected";
 $("connection").style.color="var(--ok)";
}

async function update(){
 try{
   const r=await fetch("/api/data",{cache:"no-store"});
   if(!r.ok) throw new Error("HTTP "+r.status);
   render(await r.json());
 }catch(e){
   $("connection").textContent="Disconnected";
   $("connection").style.color="var(--bad)";
   $("error").textContent="Dashboard connection error: "+e.message;
 }
}

update();
setInterval(update,2000);
</script>
</body>
</html>
)rawliteral";


// ======================== HELPERS ============================

String jsonEscape(const String &input)
{
  String out;
  out.reserve(input.length() + 16);

  for (size_t i = 0; i < input.length(); i++)
  {
    char c = input[i];

    switch (c)
    {
      case '\\': out += "\\\\"; break;
      case '"':  out += "\\\""; break;
      case '\n': out += "\\n"; break;
      case '\r': out += "\\r"; break;
      case '\t': out += "\\t"; break;
      default:   out += c; break;
    }
  }

  return out;
}

String floatJSON(float value, int decimals)
{
  if (isnan(value))
    return "null";

  return String(value, decimals);
}

String doubleJSON(double value, int decimals)
{
  if (isnan(value))
    return "null";

  return String(value, decimals);
}

int clampInt(int value, int low, int high)
{
  if (value < low) return low;
  if (value > high) return high;
  return value;
}

float adcToPercent(int raw, int dryADC, int wetADC)
{
  if (dryADC == wetADC)
    return NAN;

  float percentage =
      100.0f * ((float)dryADC - (float)raw) /
      ((float)dryADC - (float)wetADC);

  if (percentage < 0) percentage = 0;
  if (percentage > 100) percentage = 100;

  return percentage;
}


// ================= SENSOR INTERPRETATION =====================

String temperatureState(float value)
{
  if (isnan(value))
    return "Unavailable";

  if (value < 15)
    return "Cool";

  if (value < 25)
    return "Comfortable";

  if (value < 32)
    return "Warm";

  return "Hot";
}

String humidityState(float value)
{
  if (isnan(value))
    return "Unavailable";

  if (value < 30)
    return "Dry";

  if (value < 60)
    return "Moderate";

  if (value < 80)
    return "Humid";

  return "Very humid";
}

String pressureState(float value)
{
  if (isnan(value))
    return "Unavailable";

  if (value < 1000)
    return "Low pressure";

  if (value <= 1025)
    return "Normal range";

  return "High pressure";
}

String skyCondition(float lux)
{
  if (isnan(lux))
    return "Unavailable";

  // This is an interpretation from light intensity,
  // not an astronomical weather classification.
  if (lux < 10)
    return "Dark";

  if (lux < 100)
    return "Very dim";

  if (lux < 1000)
    return "Overcast / low light";

  if (lux < 10000)
    return "Bright daylight";

  return "Sunny";
}

String rainState(float percentage)
{
  if (isnan(percentage))
    return "Unavailable";

  if (percentage < 10)
    return "Dry";

  if (percentage < 35)
    return "Slight moisture";

  if (percentage < 70)
    return "Wet";

  return "Rain detected";
}

String soilState(float percentage)
{
  if (isnan(percentage))
    return "Unavailable";

  if (percentage < 20)
    return "Very dry";

  if (percentage < 40)
    return "Dry";

  if (percentage < 70)
    return "Good moisture";

  return "Very wet";
}


// ======================== GPS ================================

void updateGPS()
{
  while (GPS.available())
  {
    gps.encode(GPS.read());
  }

  if (gps.location.isValid())
  {
    gpsFix = true;
    latitude = gps.location.lat();
    longitude = gps.location.lng();
  }
  else
  {
    gpsFix = false;
  }

  if (gps.satellites.isValid())
    satellites = gps.satellites.value();
  else
    satellites = 0;
}


// ====================== SENSOR READ ==========================

void readSensors()
{
  // ---------------- DHT11 ----------------
  if (dhtOK)
  {
    float newHumidity = dht.readHumidity();
    float newTemperature = dht.readTemperature();

    if (!isnan(newHumidity) && !isnan(newTemperature))
    {
      humidity = newHumidity;
      temperature = newTemperature;
      dhtReadingOK = true;
    }
    else
    {
      dhtReadingOK = false;
      humidity = NAN;
      temperature = NAN;
    }
  }
  else
  {
    dhtReadingOK = false;
    humidity = NAN;
    temperature = NAN;
  }

  // ---------------- BMP280 ----------------
  if (bmpOK)
  {
    float t = bmp.readTemperature();
    float p = bmp.readPressure() / 100.0F;

    if (!isnan(t) && !isnan(p) && p > 0)
    {
      bmpTemperature = t;
      pressure = p;
      altitude = bmp.readAltitude(1013.25);
      bmpReadingOK = true;
    }
    else
    {
      bmpReadingOK = false;
      bmpTemperature = NAN;
      pressure = NAN;
      altitude = NAN;
    }
  }
  else
  {
    bmpReadingOK = false;
    bmpTemperature = NAN;
    pressure = NAN;
    altitude = NAN;
  }

  // ---------------- BH1750 ----------------
  if (bh1750OK)
  {
    float lux = lightMeter.readLightLevel();

    if (!isnan(lux) && lux >= 0)
    {
      lightLux = lux;
      bh1750ReadingOK = true;
    }
    else
    {
      bh1750ReadingOK = false;
      lightLux = NAN;
    }
  }
  else
  {
    bh1750ReadingOK = false;
    lightLux = NAN;
  }

  // ---------------- Analog sensors ----------------
  rainRaw = analogRead(RAIN_PIN);
  soilRaw = analogRead(SOIL_PIN);

  rainPercent = adcToPercent(
      rainRaw, RAIN_DRY_ADC, RAIN_WET_ADC);

  soilPercent = adcToPercent(
      soilRaw, SOIL_DRY_ADC, SOIL_WET_ADC);

  // ---------------- GPS ----------------
  updateGPS();
}

// ===================== JSON TELEMETRY =======================

String createTelemetryJSON()
{
  String json;
  json.reserve(900);

  json += "{";

  json += "\"node_id\":\"CE_NODE_01\",";
  json += "\"packet\":" + String(packetNumber) + ",";

  json += "\"temperature\":" + floatJSON(temperature, 2) + ",";
  json += "\"humidity\":" + floatJSON(humidity, 2) + ",";

  json += "\"bmp_temperature\":" +
          floatJSON(bmpTemperature, 2) + ",";

  json += "\"pressure\":" +
          floatJSON(pressure, 2) + ",";

  json += "\"altitude\":" +
          floatJSON(altitude, 2) + ",";

  json += "\"light_lux\":" +
          floatJSON(lightLux, 2) + ",";

  json += "\"rain_raw\":" + String(rainRaw) + ",";
  json += "\"rain_percent\":" + floatJSON(rainPercent, 1) + ",";

  json += "\"soil_raw\":" + String(soilRaw) + ",";
  json += "\"soil_percent\":" + floatJSON(soilPercent, 1) + ",";

  json += "\"gps_fix\":";
  json += gpsFix ? "true," : "false,";

  if (gpsFix)
  {
    json += "\"latitude\":" +
            String(latitude, 6) + ",";

    json += "\"longitude\":" +
            String(longitude, 6) + ",";
  }
  else
  {
    json += "\"latitude\":null,";
    json += "\"longitude\":null,";
  }

  json += "\"satellites\":" + String(satellites) + ",";

  json += "\"bmp_ok\":";
  json += bmpReadingOK ? "true," : "false,";

  json += "\"bh1750_ok\":";
  json += bh1750ReadingOK ? "true," : "false,";

  json += "\"dht_ok\":";
  json += dhtReadingOK ? "true," : "false,";

  json += "\"lora_ok\":";
  json += loraOK ? "true," : "false,";

  json += "\"lora_sent\":";
  json += lastLoraSent ? "true," : "false,";

  json += "\"temperature_state\":\"" +
          jsonEscape(temperatureState(temperature)) + "\",";

  json += "\"humidity_state\":\"" +
          jsonEscape(humidityState(humidity)) + "\",";

  json += "\"pressure_state\":\"" +
          jsonEscape(pressureState(pressure)) + "\",";

  json += "\"sky_condition\":\"" +
          jsonEscape(skyCondition(lightLux)) + "\",";

  json += "\"rain_state\":\"" +
          jsonEscape(rainState(rainPercent)) + "\",";

  json += "\"soil_state\":\"" +
          jsonEscape(soilState(soilPercent)) + "\",";

  json += "\"wifi_mode\":\"" +
          jsonEscape(wifiMode) + "\",";

  json += "\"wifi_ip\":\"" +
          jsonEscape(wifiIP) + "\",";

  json += "\"error\":\"" +
          jsonEscape(lastError) + "\",";

  json += "\"raw_json\":\"" +
          jsonEscape(lastTelemetryJSON) + "\",";

  json += "\"raw_log\":\"" +
          jsonEscape(lastRawLog) + "\"";

  json += "}";

  return json;
}


// ===================== RAW OUTPUT ============================
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
void loop()
{
  server.handleClient();

  // Feed the GPS continuously so fixes are not lost while web
  // requests are being handled.
  updateGPS();

  if (millis() - lastMeasurementMillis >= 5000 ||
      lastMeasurementMillis == 0)
  {
    lastMeasurementMillis = millis();

    packetNumber++;

    // Read current sensor values.
    readSensors();

    // Create the payload BEFORE transmission.
    // lora_sent is deliberately not placed inside the packet because
    // the result of transmission is unknown until after endPacket().
    lastTelemetryJSON =
      createTelemetryJSON();

    // Send the current packet over LoRa.
    lastLoraSent =
      sendLoRa(lastTelemetryJSON);

    // Update transient error state.
    if (!loraOK)
    {
      lastError = "LoRa module unavailable.";
    }
    else if (!lastLoraSent)
    {
      lastError = "LoRa transmission failed on last packet.";
    }
    else
    {
      // Preserve non-LoRa sensor errors if any.
      if (lastError == "LoRa transmission failed on last packet." ||
          lastError == "LoRa module unavailable.")
      {
        lastError = "";
      }
    }

    // Generate the human-readable raw output AFTER the TX result
    // is known, so it matches the serial monitor.
    lastRawLog = createHumanReadableLog();

    Serial.println();
    Serial.println(lastRawLog);
  }

  delay(2);
}
